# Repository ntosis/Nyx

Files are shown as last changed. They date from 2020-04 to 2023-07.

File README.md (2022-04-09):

# Nyx
Nyx Project is a FOC algorith for PMSM Motors based on ARM STM32F446RE, DRV8304 and Simulink. 

The Project NYX is under development and the application software has been developed with Simulink. 
The PCB is not ready and based on DRV8304 fromm Texas Instruments. 
The first tries has been made on EVAL Board from Texas Instruments 'boostxl-drv8304h'

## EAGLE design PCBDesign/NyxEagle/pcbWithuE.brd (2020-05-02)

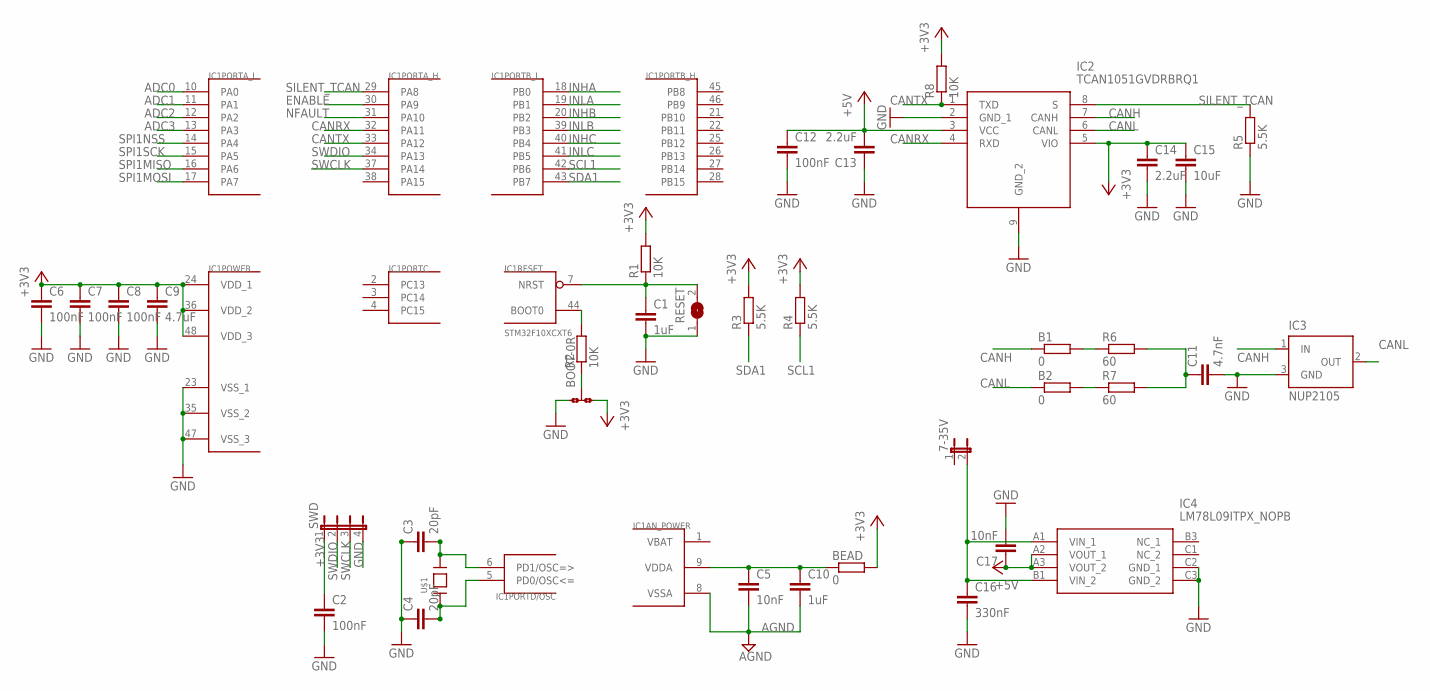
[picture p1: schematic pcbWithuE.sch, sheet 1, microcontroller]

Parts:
7-35V: JP1E; JP1
B1, B2: 0; R0805
BEAD: 0; R0805
BOOT: 0R-JUMPB; B0R-JMP
C1: 1uF; C0603
C2, C6, C7, C8: 100nF; C0603
C3, C4: 20pF; C0603
C5, C17: 10nF; C0603
C9: 4.7uF; C0805K
C10: 1uF; C0805K
C11: 4.7nF; C0402K
C12: 100nF; C0402K
C13: 2.2uF; C0402K
C14: 2.2uF; C0603K
C15: 10uF; C0603K
C16: 330nF; C0603
IC1: STM32F10XCXT6; TQFP48
IC2: TCAN1051GVDRBRQ1; DRB-8
IC3: NUP2105; SOT23
IC4: LM78L09ITPX_NOPB; BGA8C50P3X3_131X131X58
R1, R2: 10K; R0603
R3, R4: 5.5K; R0603
R5: 5.5K; R0402
R6, R7: 60; R0603
R8: 10K; R0402
RESET: SJ
SWD: JP4E; JP4
U$1: QUARZ8MHZ; SMD5*3.2MM

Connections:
+3V3: BEAD.2, BOOT.3, C2.1, C6.1, C7.1, C8.1, C9.1, C14.1, C15.1, IC1.24 (VDD_1), IC1.36 (VDD_2), IC1.48 (VDD_3), IC2.5 (VIO), R1.2, R3.2, R4.2, R8.2, SWD.1; also elsewhere on the board
+5V: C12.1, C13.2, C17.1, IC2.3 (VCC), IC4.A2 (VOUT_1), IC4.A3 (VOUT_2)
ADC0: IC1.10 (PA0)
ADC1: IC1.11 (PA1)
ADC2: IC1.12 (PA2)
ADC3: IC1.13 (PA3)
AGND: C5.2, C10.2, IC1.8 (VSSA); also elsewhere on the board
CANH: B1.1, IC2.7 (CANH), IC3.1 (IN)
CANL: B2.1, IC2.6 (CANL), IC3.2 (OUT)
CANRX: IC1.32 (PA11), IC2.4 (RXD)
CANTX: IC1.33 (PA12), IC2.1 (TXD), R8.1
ENABLE: IC1.30 (PA9); also elsewhere on the board
GND: BOOT.1, C1.2, C2.2, C3.1, C4.1, C6.2, C7.2, C8.2, C9.2, C11.2, C12.2, C13.1, C14.2, C15.2, C16.2, C17.2, IC1.23 (VSS_1), IC1.35 (VSS_2), IC1.47 (VSS_3), IC2.2 (GND_1), IC2.9 (GND_2), IC3.3 (GND), IC4.C2 (GND_1), IC4.C3 (GND_2), R5.1, RESET.1, SWD.4; also elsewhere on the board
INHA: IC1.18 (PB0); also elsewhere on the board
INHB: IC1.20 (PB2); also elsewhere on the board
INHC: IC1.40 (PB4); also elsewhere on the board
INLA: IC1.19 (PB1); also elsewhere on the board
INLB: IC1.39 (PB3); also elsewhere on the board
INLC: IC1.41 (PB5); also elsewhere on the board
unnamed: C1.1, IC1.7 (NRST), R1.1, RESET.2
unnamed: C3.2, IC1.6 (PD1/OSC=>), U$1.P$2
unnamed: C4.2, IC1.5 (PD0/OSC<=), U$1.P$1
unnamed: IC1.44 (BOOT0), R2.2
unnamed: BEAD.1, C5.1, C10.1, IC1.9 (VDDA)
unnamed: BOOT.2, R2.1
unnamed: C11.1, R6.2, R7.2
unnamed: B1.2, R6.1
unnamed: B2.2, R7.1
unnamed: 7-35V.2, C16.1, IC4.A1 (VIN_1), IC4.B1 (VIN_2)
NFAULT: IC1.31 (PA10); also elsewhere on the board
SCL1: IC1.42 (PB6), R4.1
SDA1: IC1.43 (PB7), R3.1
SILENT_TCAN: IC1.29 (PA8), IC2.8 (S), R5.2
SPI1MISO: IC1.16 (PA6)
SPI1MOSI: IC1.17 (PA7)
SPI1NSS: IC1.14 (PA4)
SPI1SCK: IC1.15 (PA5)
SWCLK: IC1.37 (PA14), SWD.3
SWDIO: IC1.34 (PA13), SWD.2
VBAT: IC1.1 (VBAT)

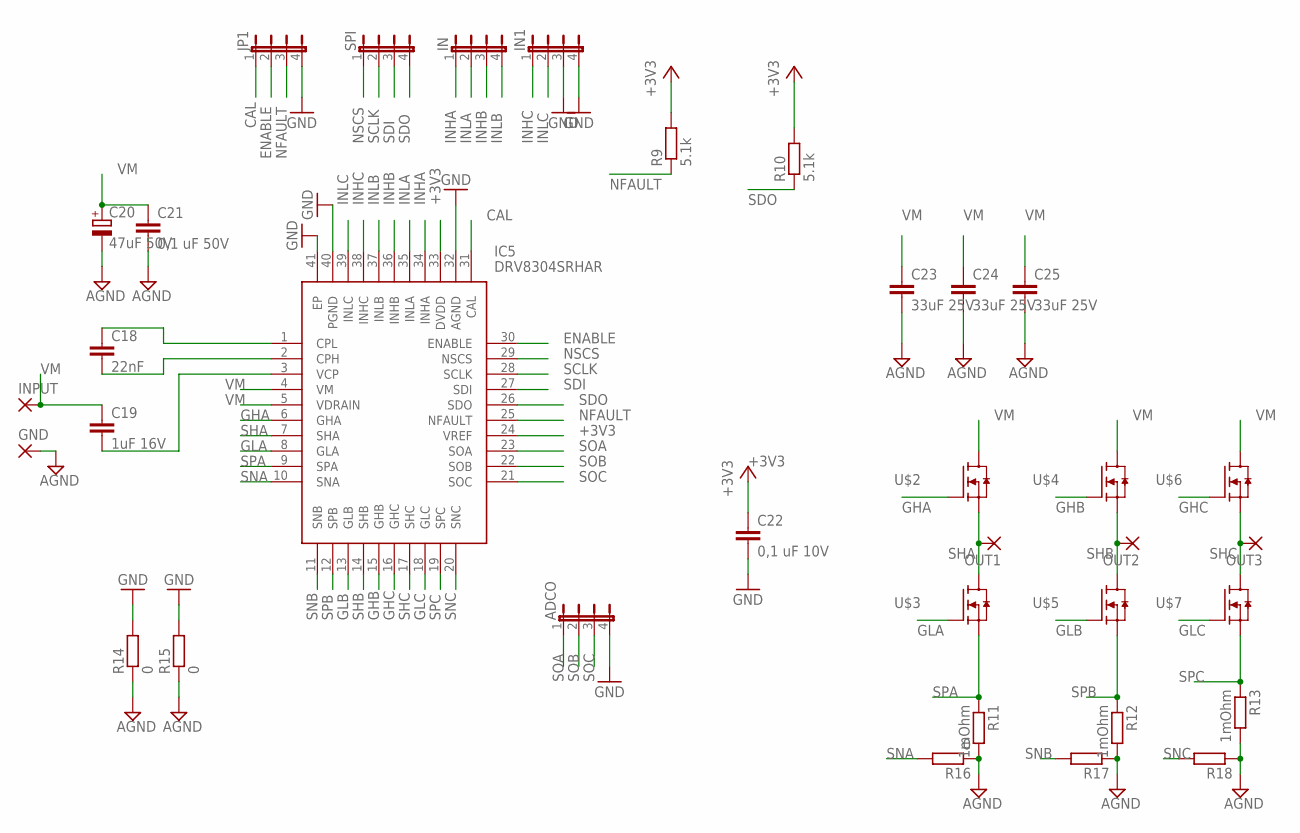
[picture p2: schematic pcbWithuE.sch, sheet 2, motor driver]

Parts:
ADCO: JP4E; JP4
C18: 22nF; C0805K
C19: 1uF 16V; C0805K
C20: 47uF 50V; E7,5-16
C21: 0,1 uF 50V; C0805K
C22: 0,1 uF 10V; C0805K
C23, C24, C25: 33uF 25V; C1206K
GND: 3,17/1,3
IC5: DRV8304SRHAR; QFN50P600X600X100-41N
IN, IN1: JP4E; JP4
INPUT: 3,17/1,3
JP1: JP4E; JP4
OUT1, OUT2, OUT3: SMD2; SMD1,27-2,54
R9, R10: 5.1k; R0805
R11, R12, R13: 1mOhm; 1216
R14, R15: 0; R0805W
R16: 0; R0201
R17, R18: R-EU_R0201; R0201
SPI: JP4E; JP4
U$2, U$3, U$4, U$5, U$6, U$7: SIRA80DP-T1-RE3-CLASSIC; SI7852ADPT1GE3

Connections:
+3V3: C22.1, IC5.24 (VREF), IC5.33 (DVDD), R9.2, R10.2; also elsewhere on the board
AGND: C20.-, C21.2, C23.2, C24.2, C25.2, GND.1, R11.P$2 (2), R11.P$4 (2), R12.P$2 (2), R12.P$4 (2), R13.P$2 (2), R13.P$4 (2), R14.1, R15.1, R16.1, R17.1, R18.1; also elsewhere on the board
CAL: IC5.31 (CAL), JP1.1
ENABLE: IC5.30 (ENABLE), JP1.2; also elsewhere on the board
GHA: IC5.6 (GHA), U$2.4 (G)
GHB: IC5.15 (GHB), U$4.4 (G)
GHC: IC5.16 (GHC), U$6.4 (G)
GLA: IC5.8 (GLA), U$3.4 (G)
GLB: IC5.13 (GLB), U$5.4 (G)
GLC: IC5.18 (GLC), U$7.4 (G)
GND: ADCO.4, C22.2, IC5.32 (AGND), IC5.40 (PGND), IC5.41 (EP), IN1.3, IN1.4, JP1.4, R14.2, R15.2; also elsewhere on the board
INHA: IC5.34 (INHA), IN.1; also elsewhere on the board
INHB: IC5.36 (INHB), IN.3; also elsewhere on the board
INHC: IC5.38 (INHC), IN1.1; also elsewhere on the board
INLA: IC5.35 (INLA), IN.2; also elsewhere on the board
INLB: IC5.37 (INLB), IN.4; also elsewhere on the board
INLC: IC5.39 (INLC), IN1.2; also elsewhere on the board
unnamed: C18.1, IC5.1 (CPL)
unnamed: C18.2, IC5.2 (CPH)
unnamed: C19.2, IC5.3 (VCP)
NFAULT: IC5.25 (NFAULT), JP1.3, R9.1; also elsewhere on the board
NSCS: IC5.29 (NSCS), SPI.1
SCLK: IC5.28 (SCLK), SPI.2
SDI: IC5.27 (SDI), SPI.3
SDO: IC5.26 (SDO), R10.1, SPI.4
SHA: IC5.7 (SHA), OUT1.1, U$2.1 (S), U$2.2 (S), U$2.3 (S), U$3.5 (D), U$3.6 (D), U$3.7 (D), U$3.8 (D), U$3.9 (D), U$3.10 (D), U$3.11 (D)
SHB: IC5.14 (SHB), OUT2.1, U$4.1 (S), U$4.2 (S), U$4.3 (S), U$5.5 (D), U$5.6 (D), U$5.7 (D), U$5.8 (D), U$5.9 (D), U$5.10 (D), U$5.11 (D)
SHC: IC5.17 (SHC), OUT3.1, U$6.1 (S), U$6.2 (S), U$6.3 (S), U$7.5 (D), U$7.6 (D), U$7.7 (D), U$7.8 (D), U$7.9 (D), U$7.10 (D), U$7.11 (D)
SNA: IC5.10 (SNA), R16.2
SNB: IC5.11 (SNB), R17.2
SNC: IC5.20 (SNC), R18.2
SOA: ADCO.1, IC5.23 (SOA)
SOB: ADCO.2, IC5.22 (SOB)
SOC: ADCO.3, IC5.21 (SOC)
SPA: IC5.9 (SPA), R11.P$1 (1), R11.P$3 (1), U$3.1 (S), U$3.2 (S), U$3.3 (S)
SPB: IC5.12 (SPB), R12.P$1 (1), R12.P$3 (1), U$5.1 (S), U$5.2 (S), U$5.3 (S)
SPC: IC5.19 (SPC), R13.P$1 (1), R13.P$3 (1), U$7.1 (S), U$7.2 (S), U$7.3 (S)
VM: C19.1, C20.+, C21.1, C23.1, C24.1, C25.1, IC5.4 (VM), IC5.5 (VDRAIN), INPUT.1, U$2.5 (D), U$2.6 (D), U$2.7 (D), U$2.8 (D), U$2.9 (D), U$2.10 (D), U$2.11 (D), U$4.5 (D), U$4.6 (D), U$4.7 (D), U$4.8 (D), U$4.9 (D), U$4.10 (D), U$4.11 (D), U$6.5 (D), U$6.6 (D), U$6.7 (D), U$6.8 (D), U$6.9 (D), U$6.10 (D), U$6.11 (D)

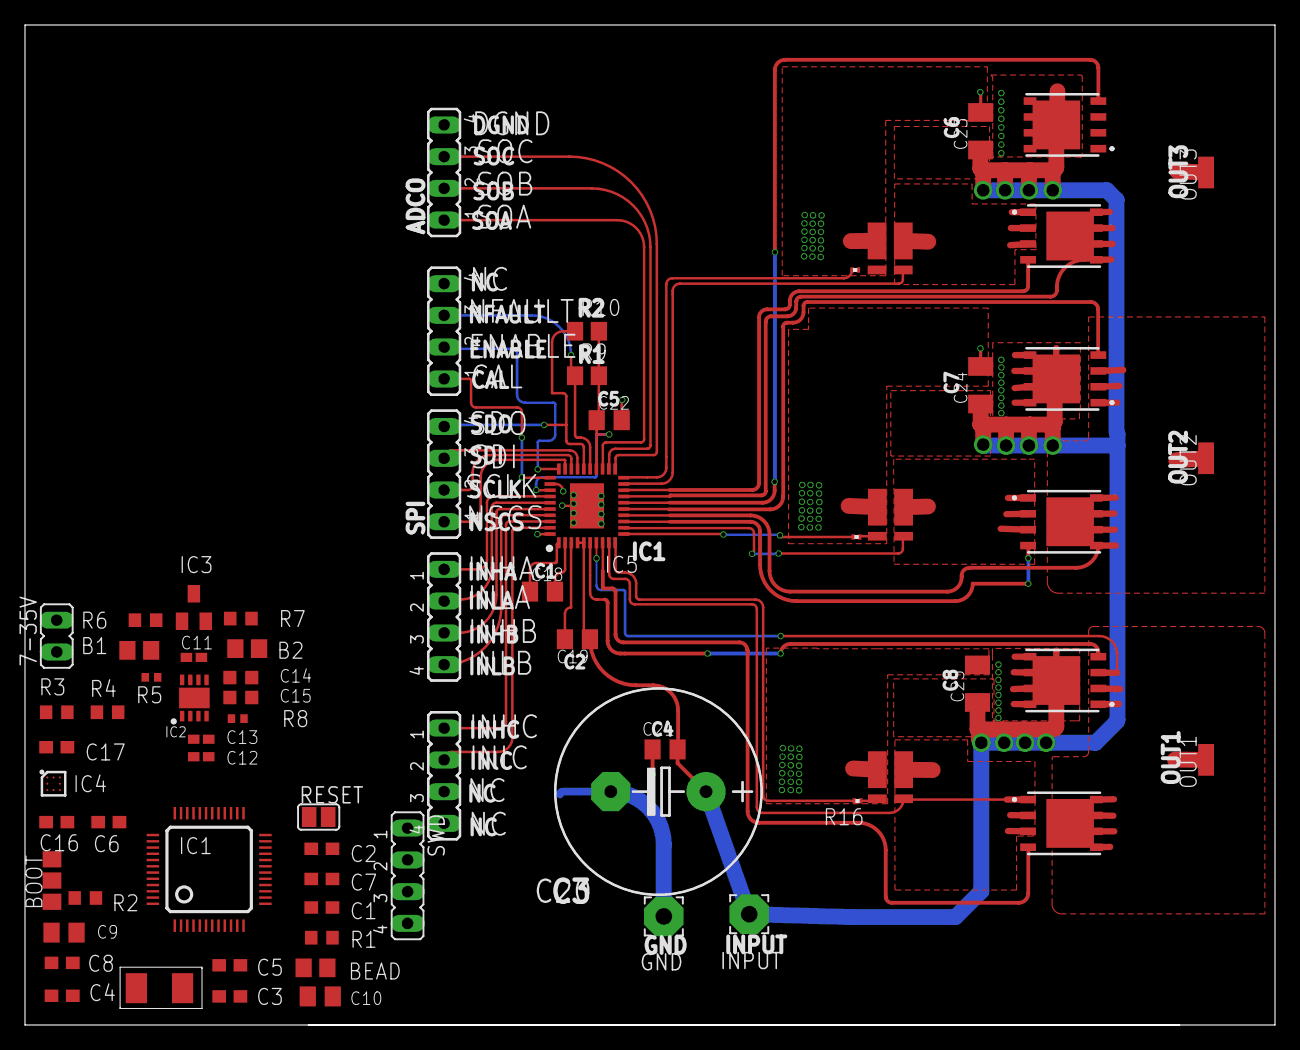
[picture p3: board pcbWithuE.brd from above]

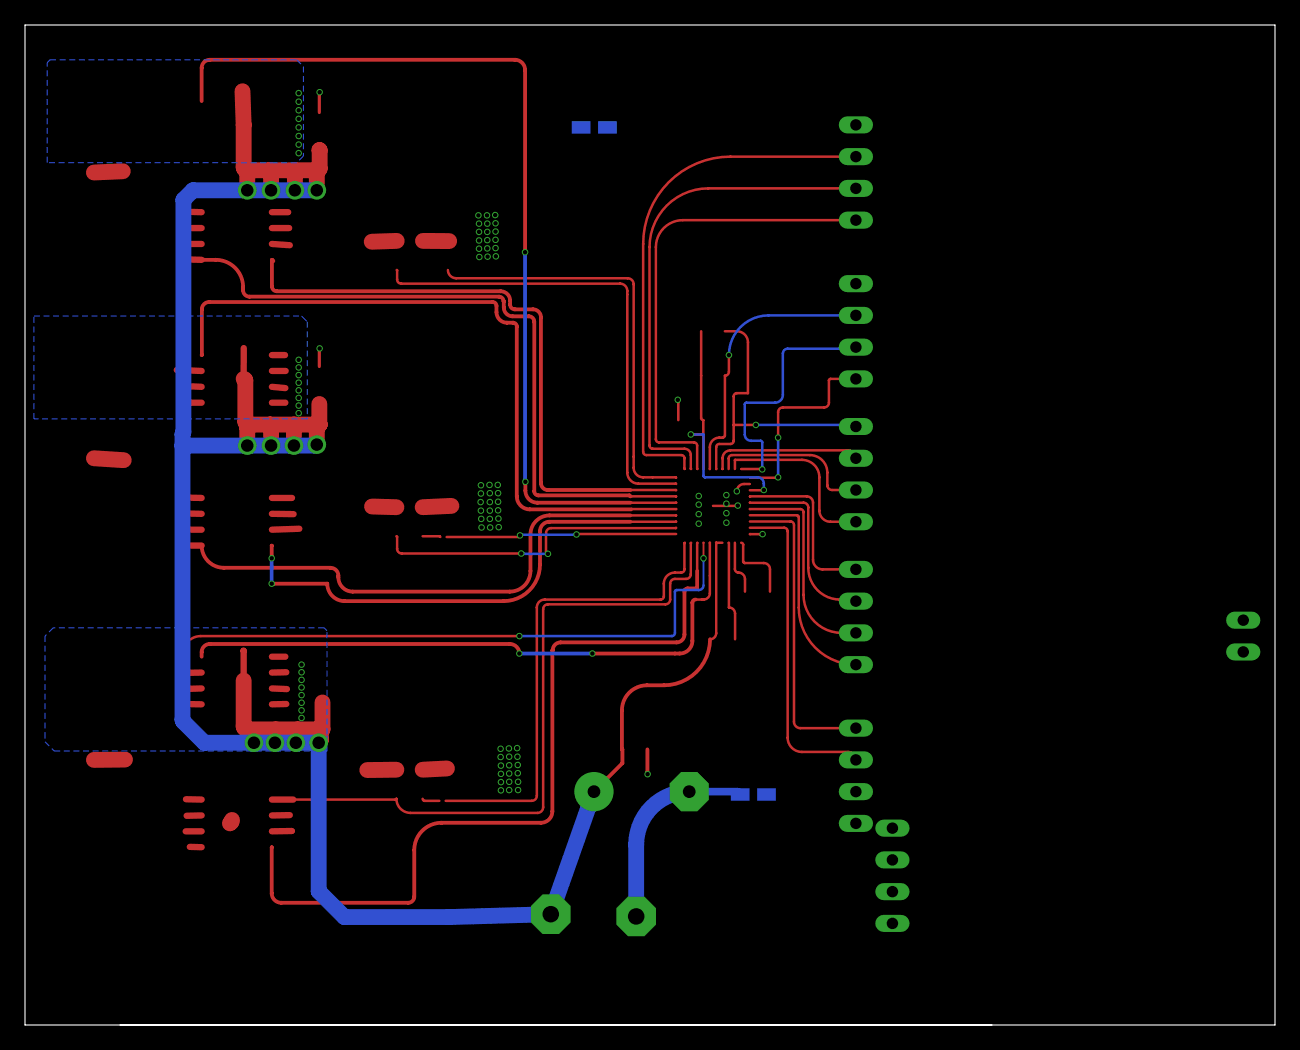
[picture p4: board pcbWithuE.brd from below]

Board: 2 copper layers, 100.0 x 80.0 mm, 72 parts (2 on the bottom side), 58 nets.

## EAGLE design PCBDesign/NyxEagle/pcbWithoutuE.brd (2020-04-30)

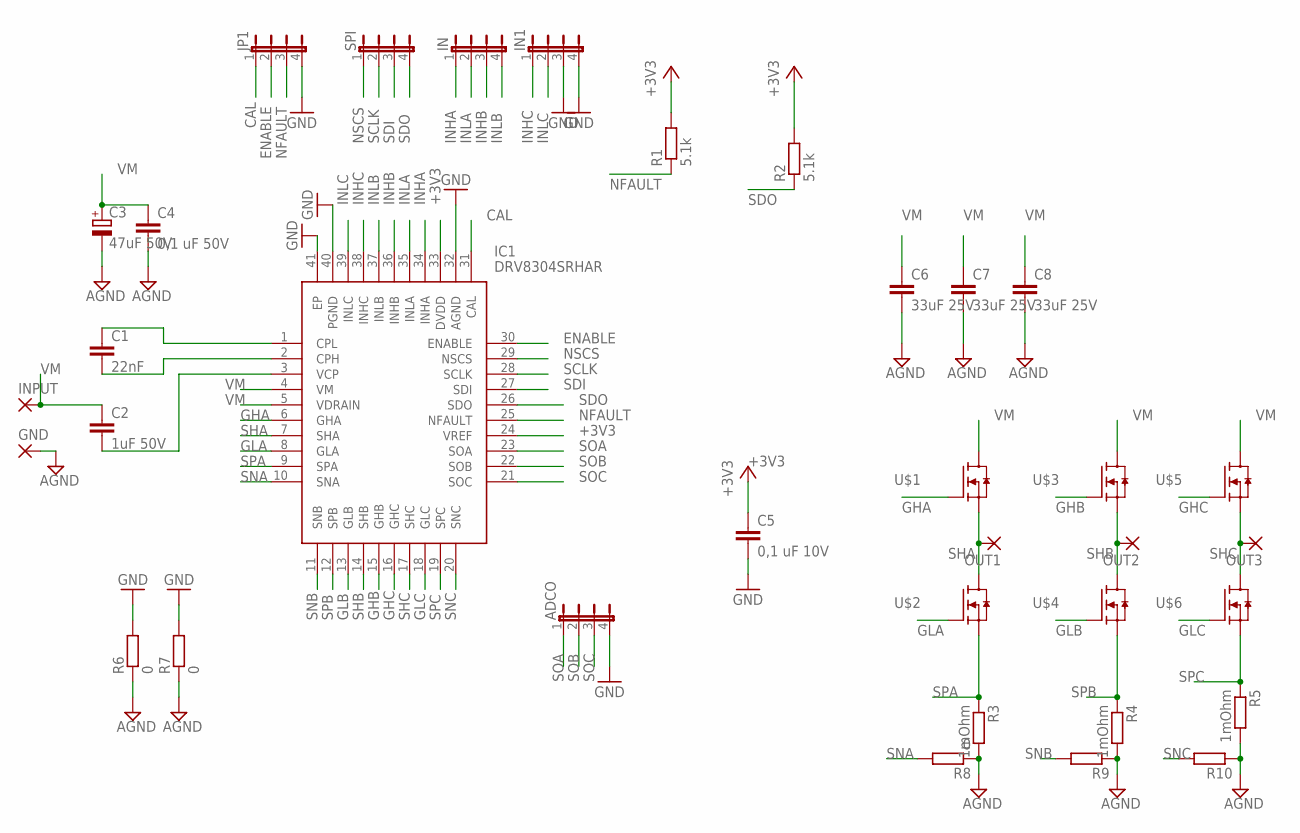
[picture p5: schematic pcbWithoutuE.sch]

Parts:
ADCO: JP4E; JP4
C1: 22nF; C0805K
C2: 1uF 50V; C0805K
C3: 47uF 50V; E7,5-16
C4: 0,1 uF 50V; C0805K
C5: 0,1 uF 10V; C0805K
C6, C7, C8: 33uF 25V; C1206K
GND: 3,17/1,3
IC1: DRV8304SRHAR; QFN50P600X600X100-41N
IN, IN1: JP4E; JP4
INPUT: 3,17/1,3
JP1: JP4E; JP4
OUT1, OUT2, OUT3: SMD2; SMD1,27-2,54
R1, R2: 5.1k; R0805
R3, R4, R5: 1mOhm; 1216
R6, R7: 0; R0805W
R8: 0; R0201
R9, R10: R-EU_R0201; R0201
SPI: JP4E; JP4
U$1, U$2, U$3, U$4, U$5, U$6: SIRA80DP-T1-RE3-CLASSIC; SI7852ADPT1GE3

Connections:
+3V3: C5.1, IC1.24 (VREF), IC1.33 (DVDD), R1.2, R2.2
AGND: C3.-, C4.2, C6.2, C7.2, C8.2, GND.1, R3.P$2 (2), R3.P$4 (2), R4.P$2 (2), R4.P$4 (2), R5.P$2 (2), R5.P$4 (2), R6.1, R7.1, R8.1, R9.1, R10.1
CAL: IC1.31 (CAL), JP1.1
ENABLE: IC1.30 (ENABLE), JP1.2
GHA: IC1.6 (GHA), U$1.4 (G)
GHB: IC1.15 (GHB), U$3.4 (G)
GHC: IC1.16 (GHC), U$5.4 (G)
GLA: IC1.8 (GLA), U$2.4 (G)
GLB: IC1.13 (GLB), U$4.4 (G)
GLC: IC1.18 (GLC), U$6.4 (G)
GND: ADCO.4, C5.2, IC1.32 (AGND), IC1.40 (PGND), IC1.41 (EP), IN1.3, IN1.4, JP1.4, R6.2, R7.2
INHA: IC1.34 (INHA), IN.1
INHB: IC1.36 (INHB), IN.3
INHC: IC1.38 (INHC), IN1.1
INLA: IC1.35 (INLA), IN.2
INLB: IC1.37 (INLB), IN.4
INLC: IC1.39 (INLC), IN1.2
unnamed: C1.1, IC1.1 (CPL)
unnamed: C1.2, IC1.2 (CPH)
unnamed: C2.2, IC1.3 (VCP)
NFAULT: IC1.25 (NFAULT), JP1.3, R1.1
NSCS: IC1.29 (NSCS), SPI.1
SCLK: IC1.28 (SCLK), SPI.2
SDI: IC1.27 (SDI), SPI.3
SDO: IC1.26 (SDO), R2.1, SPI.4
SHA: IC1.7 (SHA), OUT1.1, U$1.1 (S), U$1.2 (S), U$1.3 (S), U$2.5 (D), U$2.6 (D), U$2.7 (D), U$2.8 (D), U$2.9 (D), U$2.10 (D), U$2.11 (D)
SHB: IC1.14 (SHB), OUT2.1, U$3.1 (S), U$3.2 (S), U$3.3 (S), U$4.5 (D), U$4.6 (D), U$4.7 (D), U$4.8 (D), U$4.9 (D), U$4.10 (D), U$4.11 (D)
SHC: IC1.17 (SHC), OUT3.1, U$5.1 (S), U$5.2 (S), U$5.3 (S), U$6.5 (D), U$6.6 (D), U$6.7 (D), U$6.8 (D), U$6.9 (D), U$6.10 (D), U$6.11 (D)
SNA: IC1.10 (SNA), R8.2
SNB: IC1.11 (SNB), R9.2
SNC: IC1.20 (SNC), R10.2
SOA: ADCO.1, IC1.23 (SOA)
SOB: ADCO.2, IC1.22 (SOB)
SOC: ADCO.3, IC1.21 (SOC)
SPA: IC1.9 (SPA), R3.P$1 (1), R3.P$3 (1), U$2.1 (S), U$2.2 (S), U$2.3 (S)
SPB: IC1.12 (SPB), R4.P$1 (1), R4.P$3 (1), U$4.1 (S), U$4.2 (S), U$4.3 (S)
SPC: IC1.19 (SPC), R5.P$1 (1), R5.P$3 (1), U$6.1 (S), U$6.2 (S), U$6.3 (S)
VM: C2.1, C3.+, C4.1, C6.1, C7.1, C8.1, IC1.4 (VM), IC1.5 (VDRAIN), INPUT.1, U$1.5 (D), U$1.6 (D), U$1.7 (D), U$1.8 (D), U$1.9 (D), U$1.10 (D), U$1.11 (D), U$3.5 (D), U$3.6 (D), U$3.7 (D), U$3.8 (D), U$3.9 (D), U$3.10 (D), U$3.11 (D), U$5.5 (D), U$5.6 (D), U$5.7 (D), U$5.8 (D), U$5.9 (D), U$5.10 (D), U$5.11 (D)

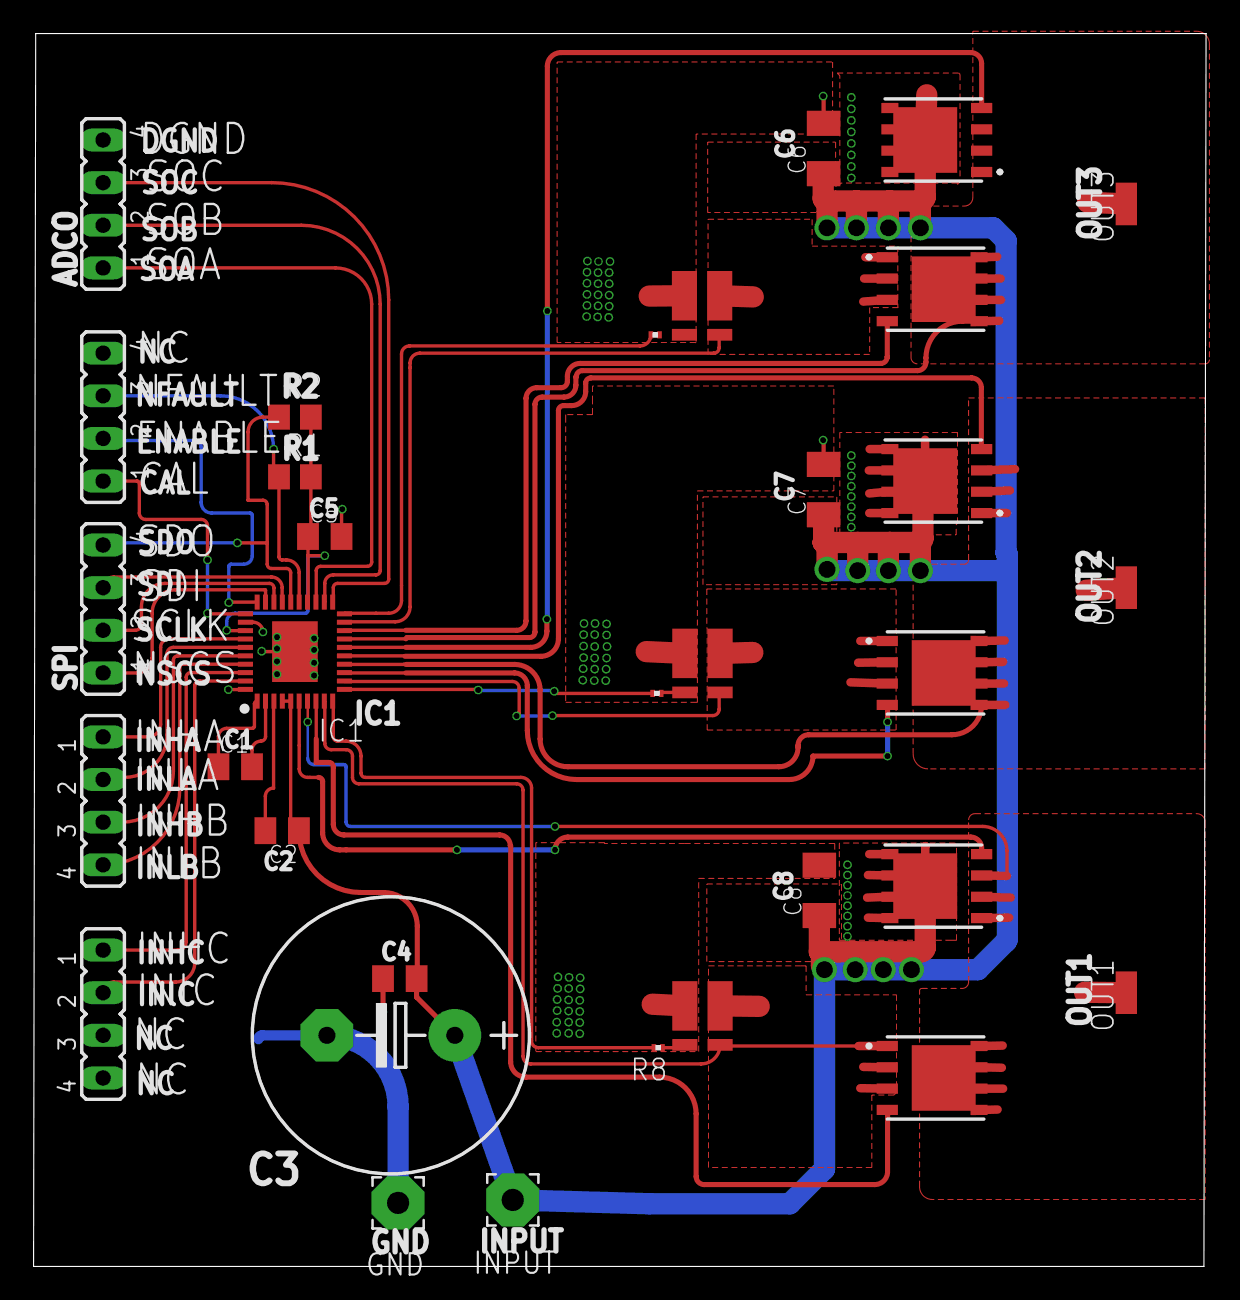
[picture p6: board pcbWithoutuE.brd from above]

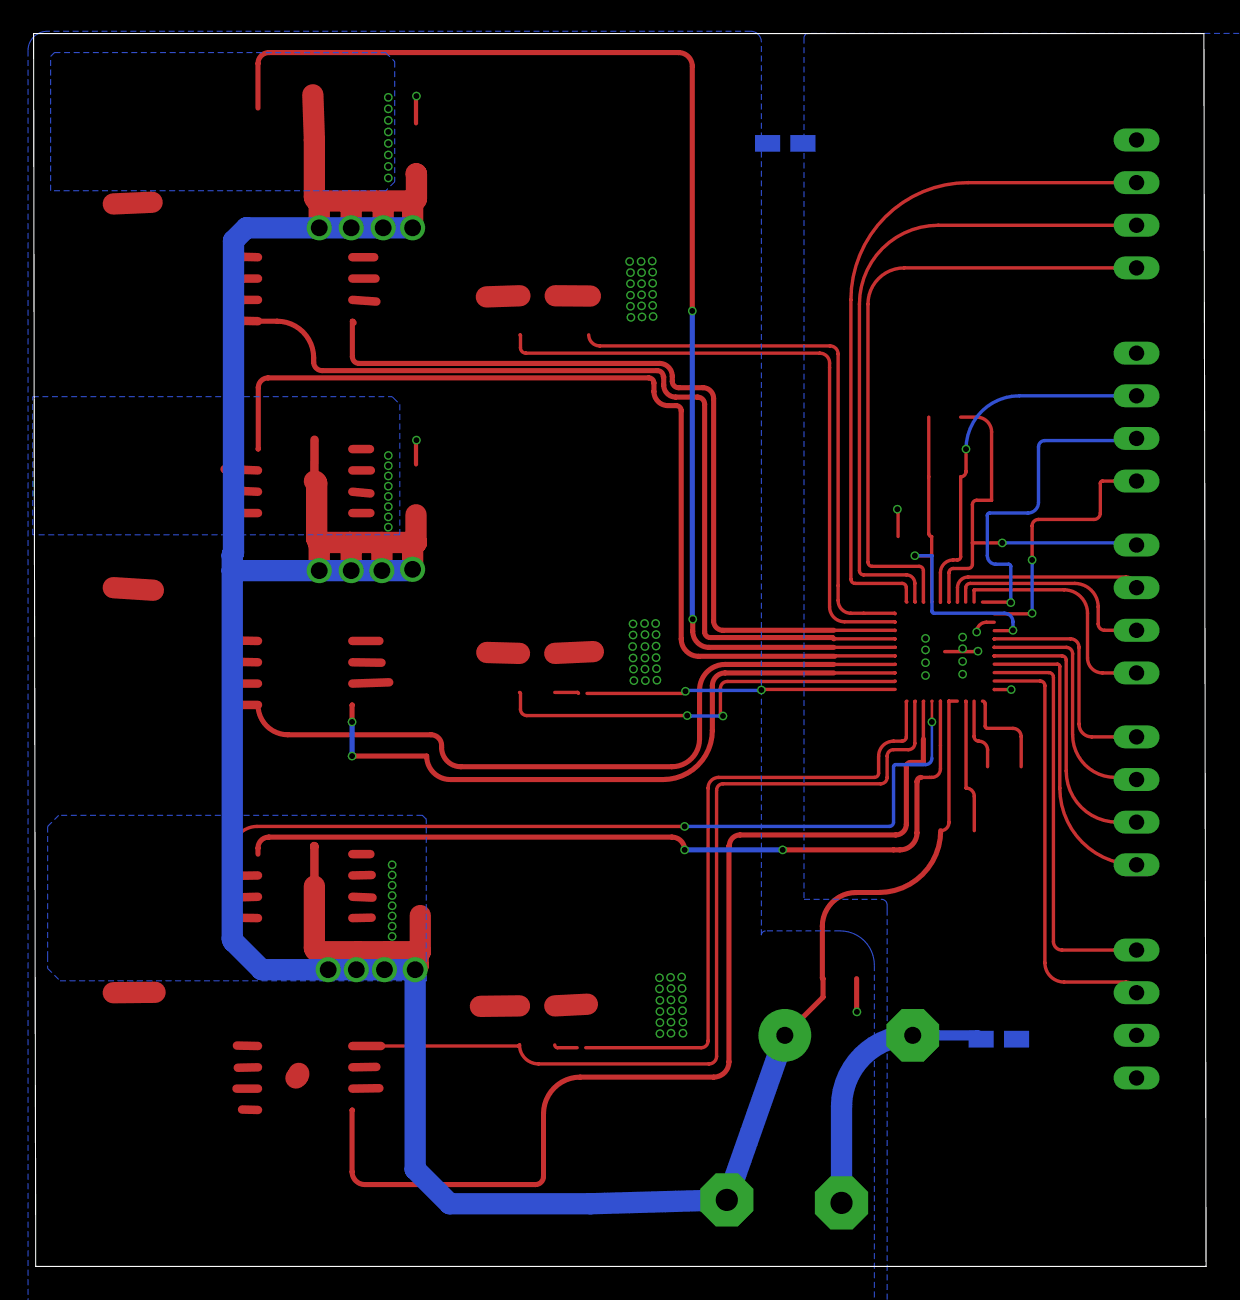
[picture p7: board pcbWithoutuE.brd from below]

Board: 2 copper layers, 69.9 x 73.4 mm, 35 parts (2 on the bottom side), 38 nets.

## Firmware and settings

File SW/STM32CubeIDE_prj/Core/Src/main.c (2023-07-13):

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
/* Includes ------------------------------------------------------------------*/
#include "main.h"
#include "cmsis_os.h"
#include "adc.h"
#include "spi.h"
#include "tim.h"
#include "usart.h"
#include "gpio.h"

/* USER CODE BEGIN Includes */

#include "MotorControlLib.h"
#include "MotorControlLib_types.h"
#include "InterfaceBswApp.h"
#include "limits.h"
/* USER CODE END Includes */

/* USER CODE BEGIN PD */
volatile uint16_t ICValueFalling=0;
volatile uint16_t ICValueRising=0;
/* USER CODE END PD */

/* USER CODE BEGIN PM */
#define  ARM_CM_DEMCR      (*(uint32_t *)0xE000EDFC)

#define  ARM_CM_DWT_CTRL   (*(uint32_t *)0xE0001000)

#define  ARM_CM_DWT_CYCCNT (*(uint32_t *)0xE0001004)
/* USER CODE END PM */


/* USER CODE BEGIN PV */
extern void initialise_monitor_handles(void);
/* USER CODE END PV */

void SystemClock_Config(void);
void MX_FREERTOS_Init(void);
static void MX_NVIC_Init(void);
/* USER CODE BEGIN PFP */
volatile uint16_t adcBuffer[3]; // Buffer for store the results of the ADC conversion
volatile uint16_t DmaBuffer[3]; // Buffer for store the results of the ADC-DMA conversion
int16_t autoCalADCVal[2];
volatile uint16_t Duty;
uint32_t PWMICTimerSpeed;
volatile uint8_t switch_dca_input=0;
RCC_ClkInitTypeDef ClockInfos;
uint8_t zero=0;
/* USER CODE END PFP */

/**
  * @brief  The application entry point.
  * @retval int
  */
int main(void)
{
  /* MCU Configuration--------------------------------------------------------*/

  /* Reset of all peripherals, Initializes the Flash interface and the Systick. */
  HAL_Init();

  /* USER CODE BEGIN Init */
  DebugCntr = ((uint32_t*) 0xE0001004);
  /* USER CODE END Init */

  /* Configure the system clock */
  SystemClock_Config();

  /* USER CODE BEGIN SysInit */
  //MX_DMA_Init();
  /* USER CODE END SysInit */

  /* Initialize all configured peripherals */
  MX_GPIO_Init();
  MX_USART2_UART_Init();
  MX_ADC1_Init();
  MX_TIM8_Init();
  MX_SPI2_Init();
  MX_TIM5_Init();
  MX_TIM10_Init();
  MX_TIM1_Init();
  MX_TIM4_Init();
  MX_TIM2_Init();

  /* Initialize interrupts */
  MX_NVIC_Init();
  /* USER CODE BEGIN 2 */
  SET_BIT(htim8.Instance->CR1,TIM_CR1_URS); //Set timer overflow as interrupt source.
  SET_BIT(htim5.Instance->CR1,TIM_CR1_URS); //Set timer overflow as interrupt source.
  SET_BIT(htim5.Instance->DIER,TIM_DIER_UIE); //Enable interrupt.
  MotorControlLib_initialize();
  //ConvertPWMtoAngle(&zero);
  //PWMICTimerSpeed = CalculateTimerSpeedForPWMInput(&htim8); /* Todo check the correct clock to be used for pwm IC*/
#ifdef SEMIHOSTING
  initialise_monitor_handles(); /* Semihosting specific*/
#endif
  /* USER CODE END 2 */

  /* Init scheduler */
  osKernelInitialize();  /* Call init function for freertos objects (in freertos.c) */
  MX_FREERTOS_Init();
  /* Start scheduler */
  osKernelStart();

  /* We should never get here as control is now taken by the scheduler */
  /* Infinite loop */
  /* USER CODE BEGIN WHILE */
  while (1)
  {
    /* USER CODE END WHILE */

    /* USER CODE BEGIN 3 */
  }
  /* USER CODE END 3 */
}

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
/* USER CODE BEGIN 4 */
 void HAL_TIM_IC_CaptureCallback(TIM_HandleTypeDef *htim)
{

	 if (htim->Instance == TIM8) {

		 static uint8_t isTheFirstRisingEdgeAfterReset=1U;
		 float resDiv=0.0f;
		 uint16_t Dutytmp;

		 Dutytmp = Duty; //store old value for more security.

		 if ((htim->Channel == HAL_TIM_ACTIVE_CHANNEL_1)&(isTheFirstRisingEdgeAfterReset))  //rising edge after reset
		 	 {

			 isTheFirstRisingEdgeAfterReset = 0U; // Reset State


			 Duty = 0U;
		}
		else if ((htim->Channel == HAL_TIM_ACTIVE_CHANNEL_1)&(!(isTheFirstRisingEdgeAfterReset))) { // rising edge

			hasTimer8Overflowed = 0U;
			ICValueRising = HAL_TIM_ReadCapturedValue(htim, TIM_CHANNEL_1); //measures all the pulse time on + off,add on for the first clock
			ICValueFalling = HAL_TIM_ReadCapturedValue(htim, TIM_CHANNEL_2); //check if it is the first read

			if(ICValueRising < ICValueFalling) {

				// pwm input is not valid
				Duty = Dutytmp; //use the old value
				hasMathOverflowed_PWMin = 1U;
				countWrongSignals++;

				return;
			}
			else {
			//signal is valid

				if(ICValueRising != 0) {
				//avoid divion with zero
				   resDiv = ((float)ICValueFalling)/((float)ICValueRising);
				   Duty = (uint16_t)(resDiv * 4096.0f);
				   hasPWMSignalbeenread = 1;
				}
				else {
					// division with zero could occurred

					hasMathOverflowed_PWMin = 1U;
					Duty = Dutytmp; //use the old value
					return;
				}

			}

		}

		else if ((htim->Channel == HAL_TIM_ACTIVE_CHANNEL_2)&(!(isTheFirstRisingEdgeAfterReset))) {// falling edge
			/* ICValueRising = HAL_TIM_ReadCapturedValue(htim, TIM_CHANNEL_1); //measures all the pulse time on + off,add on for the first clock
			ICValueFalling = HAL_TIM_ReadCapturedValue(htim, TIM_CHANNEL_2); //check if it is the first read

			 eq : Duty = ((ICValueRising - ICValueFalling) * 100)/4096;
			* uint32 is a long integer in this configuration.
			if (__builtin_usubl_overflow(ICValueRising,ICValueFalling,&resSub))  {
			    // overflowed
			    Duty = 0;
			    hasMathOverflowed_PWMin = 1;
			}
			else {

				if (__builtin_umull_overflow(resSub,4096,&resMul)) {
					// overflowed
					Duty = 0;
					hasMathOverflowed_PWMin = 1;
				}
				else {
					// if we reach this, we have the correct result.
					Duty = (uint16_t)(resMul/ICValueRising);
				}

			}
		*/}
		 // trap, should never occur
		 if(Duty>4096) {
			 qSoll=0;
			 set_PWM_A_DT(250U);
			 set_PWM_B_DT(250U);
			 set_PWM_C_DT(250U);
			 while(1){}
		 }
	 }
	 else { // not TIM8

		 //nothing to do
	 }
}

/* USER CODE END 4 */

/**
  * @brief  Period elapsed callback in non blocking mode
  * @note   This function is called  when TIM6 interrupt took place, inside
  * HAL_TIM_IRQHandler(). It makes a direct call to HAL_IncTick() to increment
  * a global variable "uwTick" used as application time base.
  * @param  htim : TIM handle
  * @retval None
  */
void HAL_TIM_PeriodElapsedCallback(TIM_HandleTypeDef *htim)
{
  /* USER CODE BEGIN Callback 0 */
	if(htim->Instance==TIM5)
	  {
		static char firstCall=0; /* After Reset the uC calls the routine without reason TODO */
		if(firstCall!=0) {
			/* this is the interrupt routine when the timer 5 overflows in encoder mode. TIM5 is the sensor for the motor rotation   */
			if (EncoderCounterHasOverflowed==1) {
				/* set error, this is not normal */
				EncoderCounterHasOverflowedErrorFlag = 1;
			}
			else {
				/* the timer has overflowed */
				EncoderCounterHasOverflowed = 1;
			}
		}
		else if (firstCall==0){
			/* skip first call after reset */
			firstCall=1;
		}

		//__HAL_TIM_GET_COUNTER
	  }
  /* USER CODE END Callback 0 */
  if (htim->Instance == TIM6) {
    HAL_IncTick();
  }
  /* USER CODE BEGIN Callback 1 */
  if(htim->Instance==TIM10)
  {
	  	  if( 1/*hasPWMSignalbeenread==1 (Todo removed for testing)*/) {  /*Start the FOC code when the PWM input interrupt has been called first */

	  	  BaseType_t xHigherPriorityTaskWoken = pdFALSE;
	  	  vTaskNotifyGiveFromISR(ComputationINTHandle,&xHigherPriorityTaskWoken);
	  	  portYIELD_FROM_ISR(xHigherPriorityTaskWoken);

	  	  }
  }

  if(htim->Instance==TIM8) {

	  static uint32_t res=0U;
	  float resDiv=0.0f;

	  if (hasTimer8Overflowed < UINT8_MAX) {
		    hasTimer8Overflowed ++;
	  }

	  if (hasTimer8Overflowed > 10) { // too many overflows, signal is not present.
			Duty = 0;
			NoSignal_PWMin = 1;
			return;
	  }
	  else if(hasTimer8Overflowed < 10) {
			NoSignal_PWMin = 0;
	  }

	  ICValueRising = HAL_TIM_ReadCapturedValue(htim, TIM_CHANNEL_1); //measures all the pulse time on + off,add on for the first clock
	  ICValueFalling = HAL_TIM_ReadCapturedValue(htim, TIM_CHANNEL_2); //check if it is the first read

	  /* eq : Duty = ((ICValueRising - ICValueFalling) * 100)/4096;
	  * uint32 is a long integer in this configuration. */
	  if (__builtin_usubl_overflow(ICValueRising,ICValueFalling,&res))  {
			// overflowed

		Duty = 0;

		hasMathOverflowed_PWMin = 1;

	  }
	  else {

			if(ICValueRising != 0) {
				//avoid divion with zero
				resDiv = ((float)ICValueFalling)/((float)ICValueRising);
				Duty = (uint16_t)(resDiv * 4096.0f);
				hasPWMSignalbeenread = 1;
			}
			else {
				//do nothing
			}
		}



  }
  /* USER CODE END Callback 1 */
}

/**
  * @brief  This function is executed in case of error occurrence.
  * @retval None
  */
void Error_Handler(void)
{
  /* USER CODE BEGIN Error_Handler_Debug */
  /* User can add his own implementation to report the HAL error return state */
  __disable_irq();
  while (1)
  {
  }

  /* USER CODE END Error_Handler_Debug */
}

#ifdef  USE_FULL_ASSERT
/**
  * @brief  Reports the name of the source file and the source line number
  *         where the assert_param error has occurred.
  * @param  file: pointer to the source file name
  * @param  line: assert_param error line source number
  * @retval None
  */
void assert_failed(uint8_t *file, uint32_t line)
{
  /* USER CODE BEGIN 6 */
  /* User can add his own implementation to report the file name and line number,
     ex: printf("Wrong parameters value: file %s on line %d\r\n", file, line) */
  /* USER CODE END 6 */
}
#endif /* USE_FULL_ASSERT */

/************************ (C) COPYRIGHT STMicroelectronics *****END OF FILE****/

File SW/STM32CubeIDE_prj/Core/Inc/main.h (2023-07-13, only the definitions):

#define Blue_Button_Pin GPIO_PIN_13
#define Blue_Button_GPIO_Port GPIOC
#define TestINT_Pin GPIO_PIN_1
#define TestINT_GPIO_Port GPIOC
#define Sensor_in1_Pin GPIO_PIN_0
#define Sensor_in1_GPIO_Port GPIOA
#define Sensor_in2_Pin GPIO_PIN_1
#define Sensor_in2_GPIO_Port GPIOA
#define USART_TX_Pin GPIO_PIN_2
#define USART_TX_GPIO_Port GPIOA
#define USART_RX_Pin GPIO_PIN_3
#define USART_RX_GPIO_Port GPIOA
#define DRV_CS_Pin GPIO_PIN_6
#define DRV_CS_GPIO_Port GPIOA
#define DRV_ENABLE_Pin GPIO_PIN_7
#define DRV_ENABLE_GPIO_Port GPIOA
#define SOB_AI_Pin GPIO_PIN_5
#define SOB_AI_GPIO_Port GPIOC
#define UpSetBtn_Pin GPIO_PIN_9
#define UpSetBtn_GPIO_Port GPIOC
#define DRV_INLA_Pin GPIO_PIN_9
#define DRV_INLA_GPIO_Port GPIOA
#define TMS_Pin GPIO_PIN_13
#define TMS_GPIO_Port GPIOA
#define TCK_Pin GPIO_PIN_14
#define TCK_GPIO_Port GPIOA
#define SWO_Pin GPIO_PIN_3
#define SWO_GPIO_Port GPIOB
#define DRV_INLC_Pin GPIO_PIN_5
#define DRV_INLC_GPIO_Port GPIOB
#define PWM_INHC_Pin GPIO_PIN_6
#define PWM_INHC_GPIO_Port GPIOB
#define DRV_INLB_Pin GPIO_PIN_7
#define DRV_INLB_GPIO_Port GPIOB

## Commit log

2020-01-19 Update pcbWithoutuE.brd and pcbWithoutuE.sch
    [pcbWithoutuE.brd, pcbWithoutuE.sch]
2020-02-08 Change of shunt resistors to smaller.
    [pcbWithoutuE.brd, pcbWithoutuE.sch]
2020-02-15 PCB is ready and before the silk layer.
    [pcbWithoutuE.brd, pcbWithoutuE.sch]
2020-02-15 Silk layer is ready
    [pcbWithoutuE.brd]
2020-02-28 added forgoten polygon for VM signal in a mosfet.
    [pcbWithoutuE.brd]
2020-03-16 New IDE Project created and schematic with uE is updated.
    [pcbWithuE.brd, pcbWithuE.sch]
2020-03-19 Big in FreeRTOS changed to heap3. Configured ADC with DMA. A task is triggered every 100 us.
2020-04-30 Added the DRV8304 component, which is used to configure the IC motor driver with the same name.
    [pcbWithoutuE.brd]
2020-05-02 Changed SPI Clock Edge setting to rising edge. Added Read Register function for drv8304 and added a function to read via SPI after reset of the controller, if the chip is locked.
    [pcbWithuE.brd, pcbWithuE.sch]
2020-06-14 Added PWM Signal, fixed SPI Issue during to lock DRV8304 and added two debug derectives for the scheduller.
    [drv8304.c, drv8304.h, main.c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]
2020-06-28 Change PWM Freq to 10Khz, Change PWM Channel to CH4. Lower SPI Freq, Rearange GPIO Pins. ADC is modified to be triggered from PWM and use the DMA to copy the result to an array. Fix in DRV8304 Init C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
    [drv8304.c, drv8304.h, main.c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]
2020-06-28 This commit can turn the motor but in very bad manner.
2022-02-12 Change controller to STM32F446RE with FPU.
2022-03-09 Change Compile cfg.
    [NyxF446RE_CI_Artifact.cfg]
2022-03-13 Update InterfaceBswApp.c
    Add debounce counter variable in error reaction function.
    [InterfaceBswApp.c]
2022-03-29 Add more variables in print file
2022-04-03 We have a problem with the PWM input measurment for the angle sensor.
    [InterfaceBswApp.c, main.c]
2022-04-03 Add filter in PWM input mode in hardware and fix the c code to calculate correctly the pwm duty cycle input from the sensor.
    [NyxF446RE.ioc, main.c]
2022-04-09 Change PWM Input filter for the timer8 to be bigger.
2022-06-22 Add timer 8 counter overflow interrupt to catch PWM = 0%.
2022-06-22 Set bit URS from timer 8 manually, because CubeMX dont support this mode. That mode tells to controller to trigger the update event interrupt only when counter overflows. Rework the PWM in put algori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
    [main.c, main.h]
2022-11-20 Changed the timer configuration. Now timer 1 with N Channel is used to drive the PWM Signals. ADC has now the N Channel as Input triger, not internal but external. That means I used a copper bridge t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
2023-08-01 some fixes for the scheduller and for the interface.
    [InterfaceBswApp.c]

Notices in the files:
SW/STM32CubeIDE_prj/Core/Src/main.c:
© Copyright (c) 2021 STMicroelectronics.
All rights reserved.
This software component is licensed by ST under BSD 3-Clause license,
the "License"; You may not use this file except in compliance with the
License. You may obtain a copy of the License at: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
